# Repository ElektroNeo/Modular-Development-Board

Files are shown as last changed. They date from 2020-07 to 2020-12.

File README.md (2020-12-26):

# Modular-Development-Board
Arduino based Modular Development Board.

It has 4 breakable module;
- Humidity - Temperature Sensor and LED Module
- Light Sensor and Buzzer Module
- Power Module
- TTL to UART Converter Module

<<<<<<< HEAD
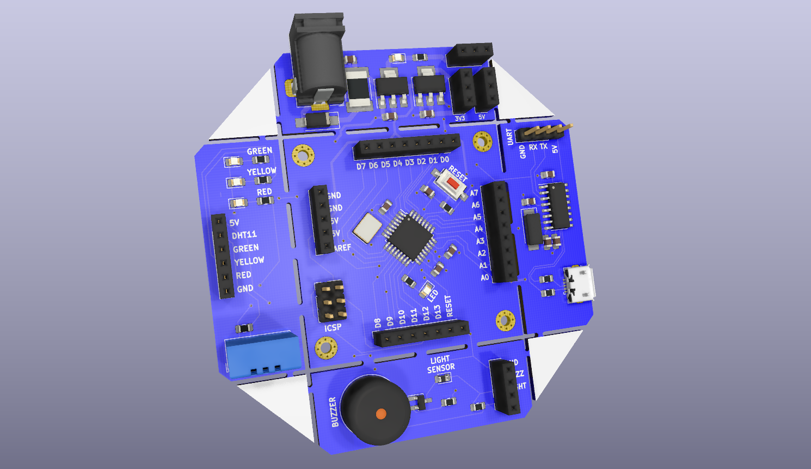
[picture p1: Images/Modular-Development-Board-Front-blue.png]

=======


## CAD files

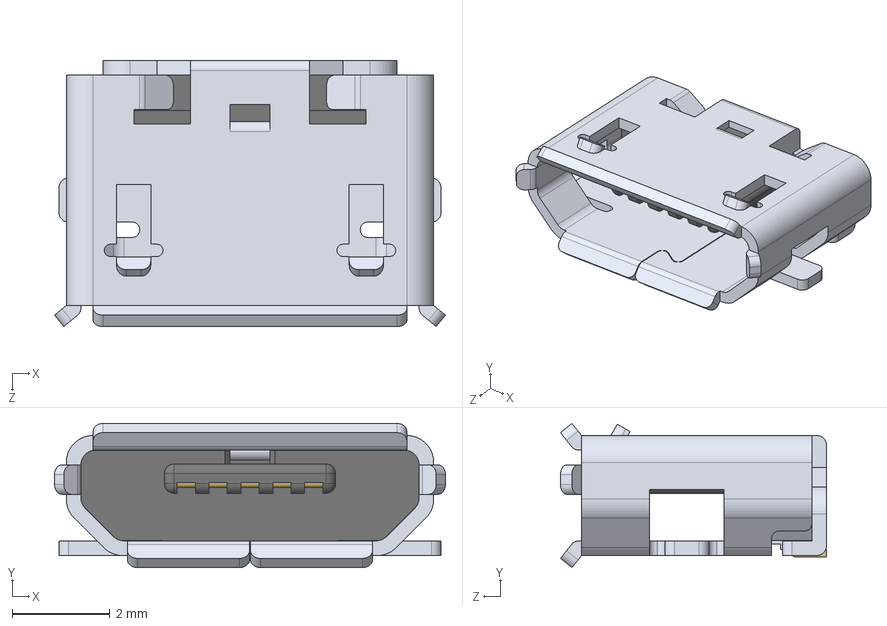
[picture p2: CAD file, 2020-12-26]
KiCAD/modular-development-board/3D-Parts/micro_usb_47346-0001.STEP
7.98 x 2.94 x 5.43 mm

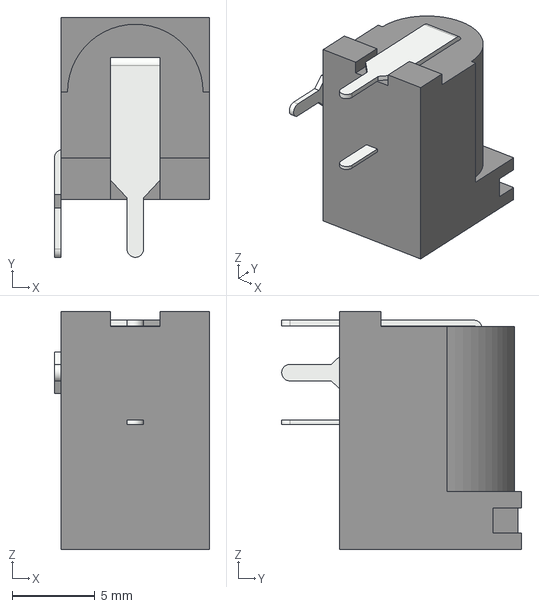
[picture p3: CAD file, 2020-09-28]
KiCAD/modular-development-board/3D-Parts/Barrel-Jack-2.1mm.STEP
9.40 x 14.5 x 14.4 mm

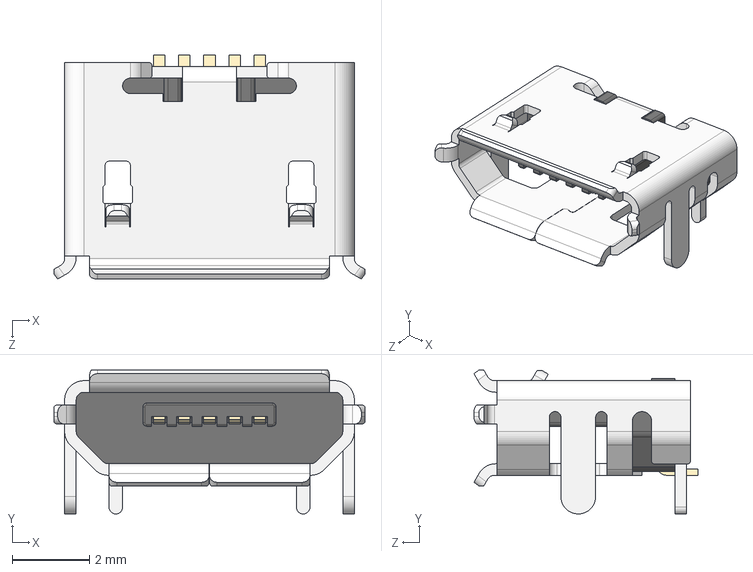
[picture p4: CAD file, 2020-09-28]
KiCAD/modular-development-board/3D-Parts/Micro USB-B Female 5Pin SMD.STEP
8.05 x 3.73 x 5.80 mm

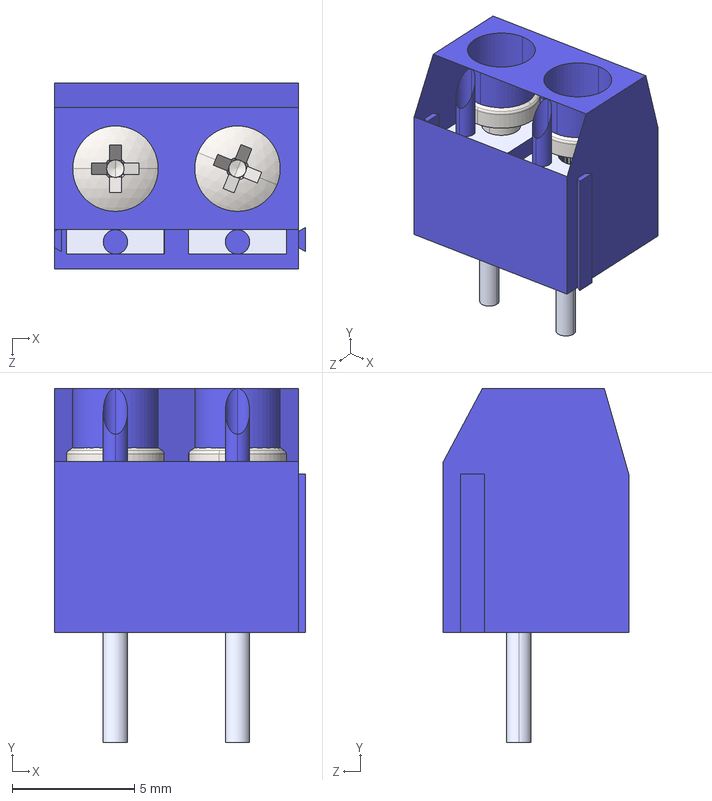
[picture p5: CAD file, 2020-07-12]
KiCAD/breakable-board/3D-Parts/ScrewTerminal.STEP
10.3 x 14.5 x 7.60 mm
ScrewTerminalCover
Pin x 2
pan head cross recess screw_iso_ISO 7045 - M2 x 3 - Z - 3N x 2

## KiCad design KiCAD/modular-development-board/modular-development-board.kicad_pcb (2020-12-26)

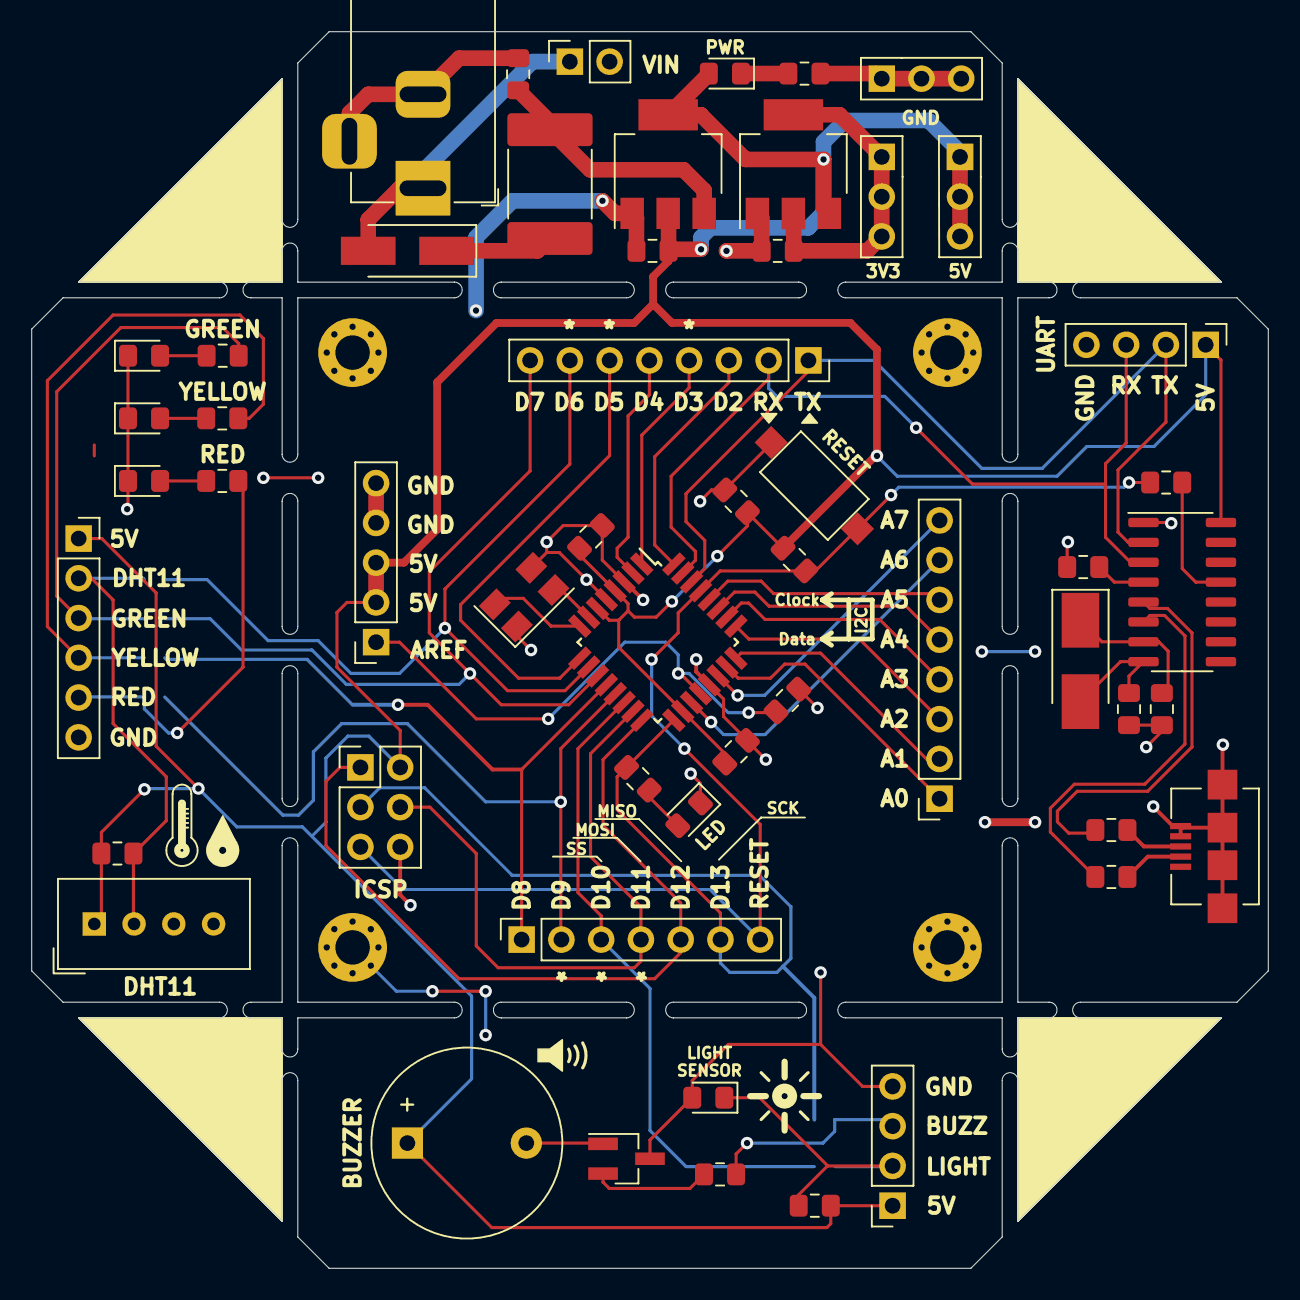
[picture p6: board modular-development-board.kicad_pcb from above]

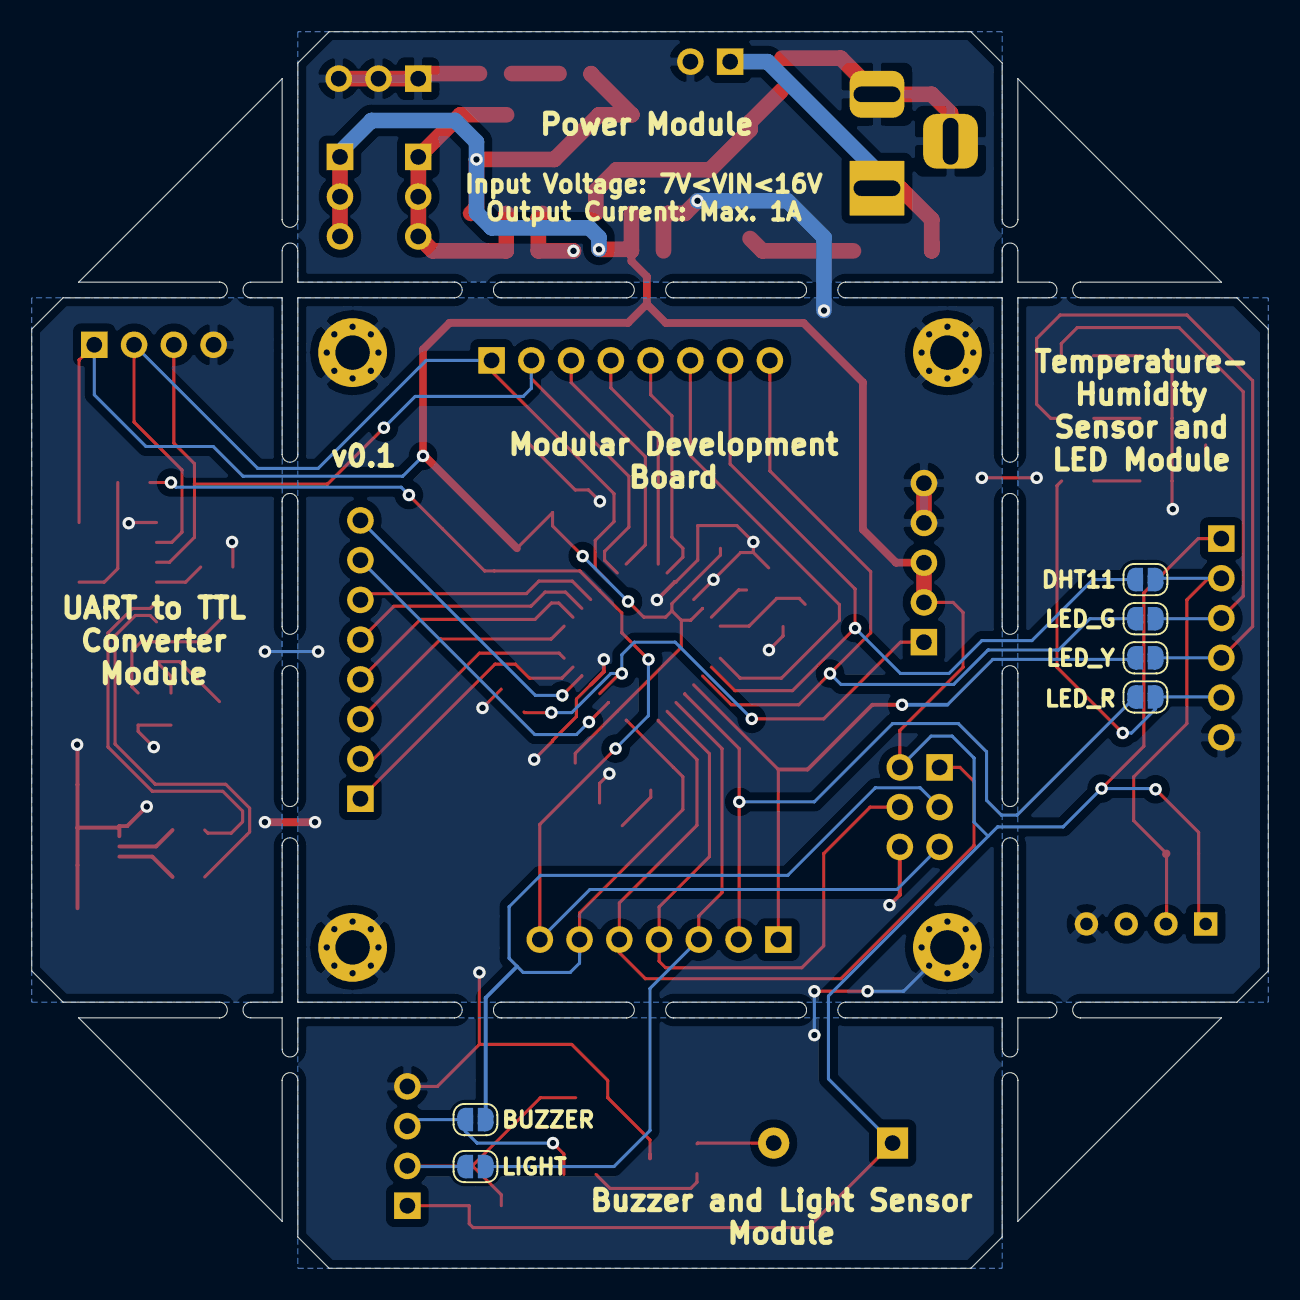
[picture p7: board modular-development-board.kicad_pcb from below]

Board: 2 copper layers, 79.0 x 79.0 mm, 64 parts (6 on the bottom side), 53 nets.

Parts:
BZ1: Buzzer; Buzzer_12x9.5RM7.6
C1, C2, C4: 100nF 50V; C_0805_2012Metric_Pad1.15x1.40mm_HandSolder
C3: 4.7uF 10V; C_0805_2012Metric_Pad1.15x1.40mm_HandSolder
C5: 22uF 25V; C_0805_2012Metric_Pad1.15x1.40mm_HandSolder
C6, C7: 10uF 10V; C_0805_2012Metric_Pad1.15x1.40mm_HandSolder
C8, C9: 10nF 50V; C_0805_2012Metric_Pad1.15x1.40mm_HandSolder
C10, C11: 18pF; C_0805_2012Metric_Pad1.15x1.40mm_HandSolder
D1: CDBA240LL-G; D_SMA_Handsoldering
D2, D3: LED; LED_0805_2012Metric_Pad1.15x1.40mm_HandSolder
D4: GREEN; LED_0805_2012Metric_Pad1.15x1.40mm_HandSolder
D5: YELLOW; LED_0805_2012Metric_Pad1.15x1.40mm_HandSolder
D6: RED; LED_0805_2012Metric_Pad1.15x1.40mm_HandSolder
F1: FSMD200-242920-R; Fuse_2920_7451Metric_Pad2.10x5.45mm_HandSolder
H1, H2, H3, H4: M4; MountingHole_2.2mm_M2_Pad_Via
J1: Power In; BarrelJack_Horizontal
J2: 5V Out; PinSocket_1x03_P2.54mm_Vertical
J3: 3V3 Out; PinSocket_1x03_P2.54mm_Vertical
J4: GND; PinSocket_1x03_P2.54mm_Vertical
J5: Digital 1; PinSocket_1x08_P2.54mm_Vertical
J6: Digital 2; PinSocket_1x07_P2.54mm_Vertical
J7: Analog; PinSocket_1x08_P2.54mm_Vertical
J8: Power; PinSocket_1x05_P2.54mm_Vertical
J9: ICSP; PinHeader_2x03_P2.54mm_Vertical
J10: DHT11-LEDS; PinSocket_1x06_P2.54mm_Vertical
J11: Buzzzer-Light; PinSocket_1x04_P2.54mm_Vertical
J12: USB_B_Micro; KLS1-233-Micro-USB
J13: UART; PinHeader_1x04_P2.54mm_Vertical
J14: Power In; PinSocket_1x02_P2.54mm_Vertical
JP1: LIGHT; SolderJumper-2_P1.3mm_Open_RoundedPad1.0x1.5mm
JP2: BUZZER; SolderJumper-2_P1.3mm_Open_RoundedPad1.0x1.5mm
JP3: DHT11; SolderJumper-2_P1.3mm_Open_RoundedPad1.0x1.5mm
JP4: LED_G; SolderJumper-2_P1.3mm_Open_RoundedPad1.0x1.5mm
JP5: LED_Y; SolderJumper-2_P1.3mm_Open_RoundedPad1.0x1.5mm
JP6: LED_R; SolderJumper-2_P1.3mm_Open_RoundedPad1.0x1.5mm
Q1: ALS-PT19-315C; D_0805_2012Metric_Pad1.15x1.40mm_HandSolder
Q2: 2N2222; SOT-23_Handsoldering
R1, R3: 1k; R_0805_2012Metric_Pad1.15x1.40mm_HandSolder
R2, R6: 1K; R_0805_2012Metric_Pad1.15x1.40mm_HandSolder
R4, R5: 22; R_0805_2012Metric_Pad1.15x1.40mm_HandSolder
R7, R8, R9: 330; R_0805_2012Metric_Pad1.15x1.40mm_HandSolder
R10, R11: 4k7; R_0805_2012Metric_Pad1.15x1.40mm_HandSolder
SW1: RESET; SW_SPST_CK_RS282G05A3
U1: ATmega328P-AU; TQFP-32_7x7mm_P0.8mm
U2: AMS1117-5.0; SOT-223-3_TabPin2
U3: AMS1117-3.3; SOT-223-3_TabPin2
U4: CH340G; SOIC-16_3.9x9.9mm_P1.27mm
U5: DHT11; Aosong_DHT11_5.5x12.0_P2.54mm
Y1: 16MHz; Crystal_SMD_5032-4Pin_5.0x3.2mm
Y2: 12MHz; Crystal_SMD_5032-2Pin_5.0x3.2mm_HandSoldering

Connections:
+3V3: C7.1, J3.1, J3.2, J3.3, U3.2
+5V: BZ1.1, C2.1, C3.1, C4.1, C6.1, D3.2, J2.1, J2.2, J2.3, J8.2, J8.3, J9.2, J10.1, J11.1, J13.1, R2.1, R6.1, R11.1, U1.4, U1.6, U1.18, U2.2, U3.3, U4.16, U5.1
/A0: J7.1, U1.23
/A1: J7.2, U1.24
/A2: J7.3, U1.25
/A3: J7.4, U1.26
/A4: J7.5, U1.27
/A5: J7.6, U1.28
/A6: J7.7, U1.19
/A7: J7.8, U1.22
/AREF: C1.1, J8.1, U1.20
/BUZZER: J11.3, JP2.1, R10.2
/D0: J5.1, J13.2, U1.30, U4.2
/D1: J5.2, J13.3, U1.31, U4.3
/D2: J5.3, U1.32
/D3: J5.4, U1.1
/D4: J5.5, U1.2
/D5: J5.6, U1.9
/D6: J5.7, JP3.2, U1.10
/D7: J5.8, JP4.2, U1.11
/D8: J6.1, JP5.2, U1.12
/D9: J6.2, JP6.2, U1.13
/D10: J6.3, JP1.2, U1.14
/D11: J6.4, J9.4, U1.15
/D12: J6.5, J9.1, U1.16
/D13: J6.6, J9.3, JP2.2, R1.2, U1.17
/D+: R4.1, U4.5
/D-: R5.1, U4.6
/DHT11: J10.2, JP3.1, R11.2, U5.2
/LED_G: J10.3, JP4.1, R7.2
/LED_R: J10.5, JP6.1, R9.2
/LED_Y: J10.4, JP5.1, R8.2
/LIGHT: J11.2, JP1.1, Q1.1, R6.2
/RESET: C9.1, J6.7, J9.5, R2.2, SW1.1, U1.29
/XI: C10.1, U4.7, Y2.1
/XO: C11.1, U4.8, Y2.2
/XTAL1: U1.7, Y1.2
/XTAL2: U1.8, Y1.4
GND: C1.2, C2.2, C3.2, C4.2, C5.2, C6.2, C7.2, C8.2, C10.2, C11.2, D2.1, D4.1, D5.1, D6.1, H1.1, H2.1, H3.1, H4.1, J1.2, J1.3, J4.1, J4.2, J4.3, J8.4, J8.5, J9.6, J10.6, J11.4, J12.4, J12.5, J12.6, J13.4, J14.2, Q1.2, Q2.3, R3.1, SW1.2, U1.3, U1.5, U1.21, U2.1, U3.1, U4.1, U5.4, Y1.1, Y1.3
unnamed: BZ1.2, Q2.1
unnamed: C8.1, U4.4
unnamed: C9.2, U4.13
unnamed: D1.1, F1.2
unnamed: D1.2, J1.1, J14.1
unnamed: D2.2, R1.1
unnamed: D3.1, R3.2
unnamed: D4.2, R7.1
unnamed: D5.2, R8.1
unnamed: D6.2, R9.1
unnamed: J12.2, R5.2
unnamed: J12.3, R4.2
unnamed: Q2.2, R10.1
VCC: C5.1, F1.1, U2.3

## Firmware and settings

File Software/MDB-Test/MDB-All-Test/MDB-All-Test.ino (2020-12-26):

#include <Adafruit_Sensor.h>
#include <DHT.h>
#include <DHT_U.h>

#define DHTPIN 6     // Digital pin connected to the DHT sensor

#define DHTTYPE    DHT11     // DHT 11

DHT_Unified dht(DHTPIN, DHTTYPE);

uint32_t delayMS;

void setup() {
  Serial.begin(9600);
  // Initialize device.
  dht.begin();
  sensor_t sensor;
  dht.temperature().getSensor(&sensor);
  dht.humidity().getSensor(&sensor);
  // Set delay between sensor readings based on sensor details.
  delayMS = sensor.min_delay / 1000;
  // initialize digital pin Buzzer/LED as an output.
  pinMode(7, OUTPUT);
  pinMode(8, OUTPUT);
  pinMode(9, OUTPUT);
  pinMode(13, OUTPUT);
}

void loop() {
  for (int i = 7; i < 10; i++) {
    digitalWrite(i, HIGH);
    digitalWrite(13, HIGH);   // turn the Buzzer/LED on
    delay(100);
    digitalWrite(i, LOW);
    digitalWrite(13, LOW);    // turn the Buzzer/LED off
    delay(100);
  }
  // Delay between measurements.
  delay(delayMS);
  // Get temperature event and print its value.
  sensors_event_t event;
  dht.temperature().getEvent(&event);
  if (isnan(event.temperature)) {
    Serial.println(F("Error reading temperature!"));
  }
  else {
    Serial.print(F("Temperature: "));
    Serial.print(event.temperature);
    Serial.println(F("°C"));
  }
  // Get humidity event and print its value.
  dht.humidity().getEvent(&event);
  if (isnan(event.relative_humidity)) {
    Serial.println(F("Error reading humidity!"));
  }
  else {
    Serial.print(F("Humidity: "));
    Serial.print(event.relative_humidity);
    Serial.println(F("%"));
  }
  int light = analogRead(A0);
  // print out the value you read:
  Serial.print("Light: ");
  Serial.println(light);
}

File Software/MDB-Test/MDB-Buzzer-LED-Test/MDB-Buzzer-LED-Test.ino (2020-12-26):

void setup() {
  // initialize digital pin Buzzer/LED as an output.
  pinMode(13, OUTPUT);
}

void loop() {
  digitalWrite(13, HIGH);   // turn the Buzzer/LED on
  delay(100);               // wait for a second
  digitalWrite(13, LOW);    // turn the Buzzer/LED off
  delay(1000);              // wait for a second
}

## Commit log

2020-07-12 Added breakable board files.
    [ScrewTerminal.STEP, breakable-board.kicad_pcb, breakable-board.sch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]
2020-09-28 Change hole size.
    [breakable-board.kicad_pcb]
2020-09-28 Added modular development board design files.
    [Barrel-Jack-2.1mm.STEP, Micro USB-B Female 5Pin SMD.STEP, modular-development-board.kicad_pcb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]
2020-12-26 Added modular developmend board design and test software.
    [micro_usb_47346-0001.STEP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]
